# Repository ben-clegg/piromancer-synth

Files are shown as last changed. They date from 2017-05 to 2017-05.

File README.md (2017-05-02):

# piromancer-synth
A Raspberry Pi based semi-modular synthesiser, using [Pyo](https://github.com/belangeo/pyo).

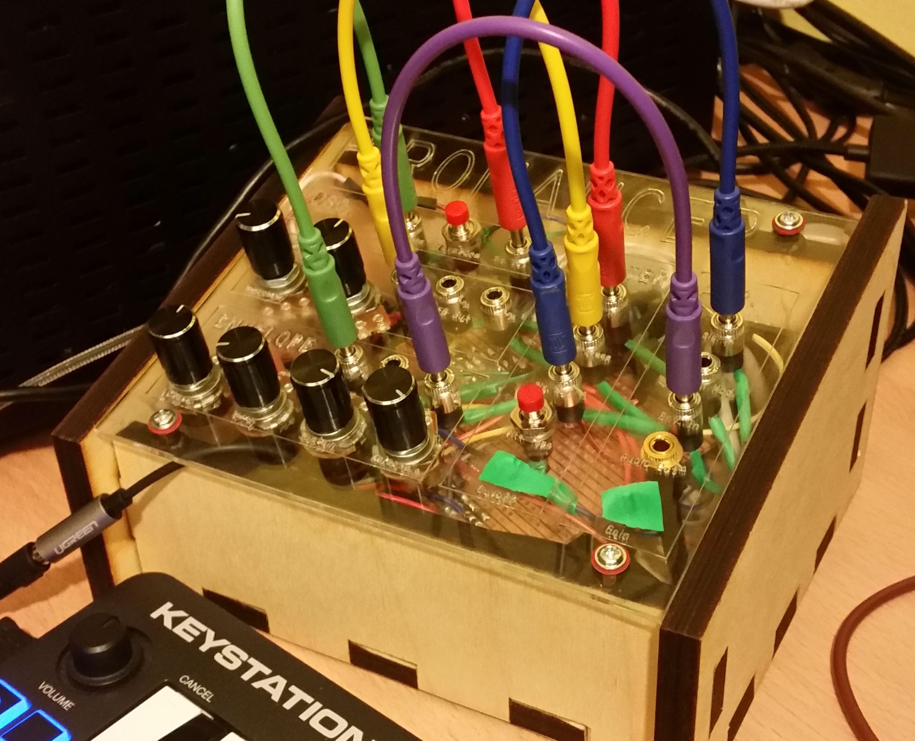
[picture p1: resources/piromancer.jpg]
The assembled synthesiser


## Licensing
All contents of this repository are released under GPLv3, with the exception of `synth/mcpaccess.py`, a modified version of [ladyada's MCP3008 driver program](https://gist.github.com/ladyada/3151375), which is released into the public domain in the same manner as the original.

## System Requirements
This software was originally designed for the original Raspberry Pi Model B, but this was confirmed to have insufficient compute power to run effectively.

However, the software functions correctly on a Raspberry Pi 3. More connections could be added due to its expanded GPIO.

## Installation
Install Jack audio server with alsa support:
```console
$ sudo apt-get install jackd2 alsaplayer-jack
```

Install [Pyo's dependencies](https://gist.github.com/pwalsh/8594869):
```console
$ sudo apt-get install python-dev libjack-jackd2-dev libportmidi-dev portaudio19-dev liblo-dev libsndfile-dev python-dev python-tk python-imaging-tk python-wxgtk2.8
```

Clone Pyo's repository, and enter its directory:
```console
$ git clone https://github.com/belangeo/pyo.git
```

[Install Pyo with Jack support, and Debian install layout](http://ajaxsoundstudio.com/pyodoc/compiling.html):
```console
$ sudo python setup.py install --install-layout=deb --use-jack
```

Provide the user with ownership of the audio output device, by adding the following to "/etc/dbus-1/system.conf":
```
<policy user="pi">
     <allow own="org.freedesktop.ReserveDevice1.Audio0"/>
</policy>
```

Clone this project's repository to the pi user's home directory:
```console
$ git clone https://github.com/BenClegg/piromancer-synth
```

## Execution
Simply run `startPiromancer.sh` to start the synthesiser. This script can be run on boot by executing `sudo crontab -e` and adding the following:
```
@reboot sh /home/pi/piromancer-synth/startPiromancer.sh >/home/pi/logs/cronlog 2>&1
```

If this "run on boot" cronjob is set, ownership of the audio output should instead be set to the root user, by changing the added code in "/etc/dbus-1/system.conf" to:
```
<policy user="root">
     <allow own="org.freedesktop.ReserveDevice1.Audio0"/>
</policy>
```

A "logs" directory should also be created inside the pi user's home directory.

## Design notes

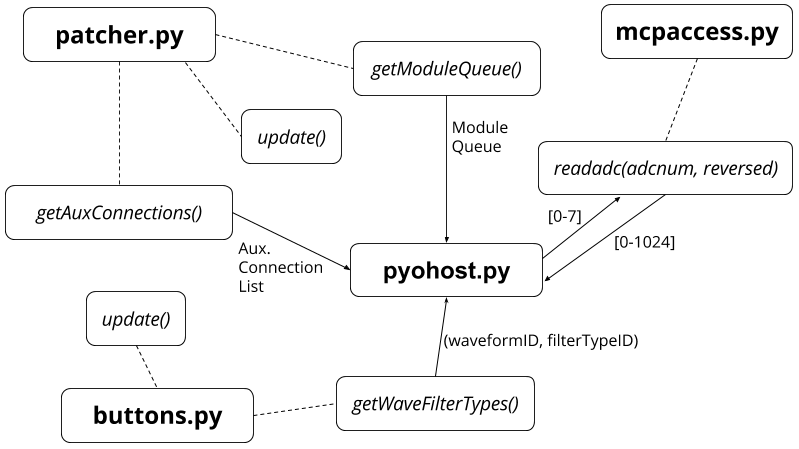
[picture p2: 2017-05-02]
resources/software-architecture.png

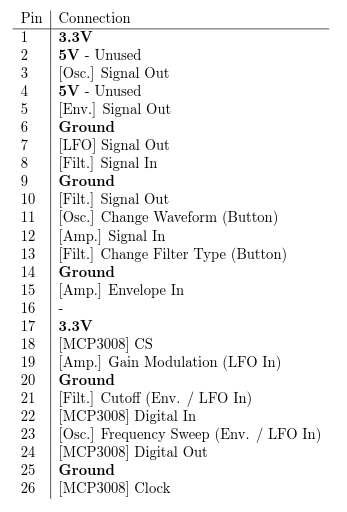
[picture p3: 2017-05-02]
resources/gpio-connections.png

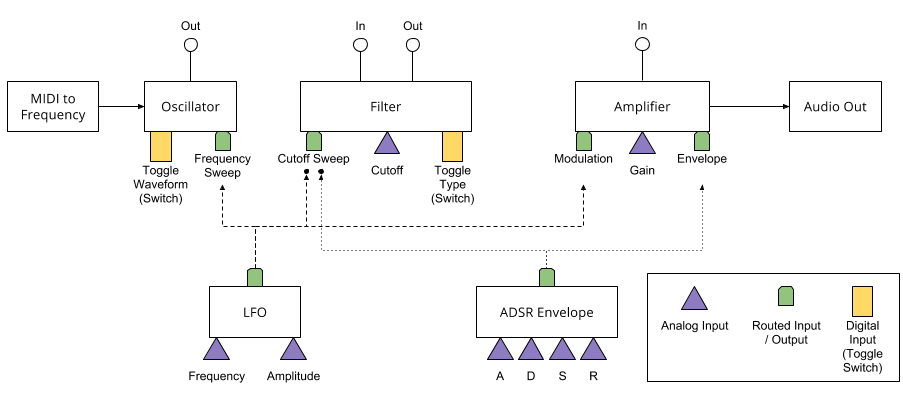
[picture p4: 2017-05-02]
resources/system-diagram.png

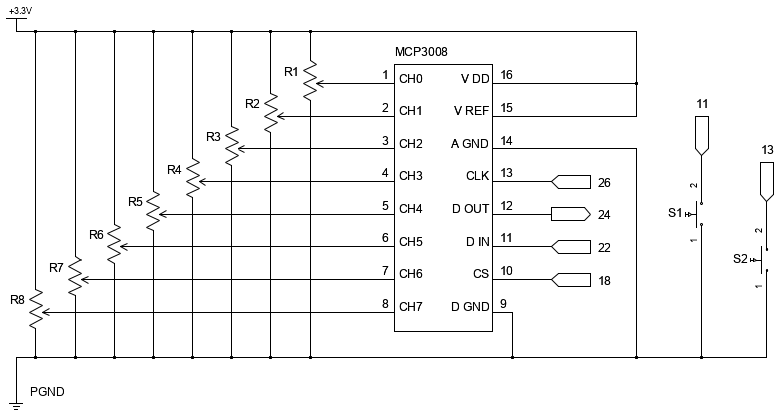
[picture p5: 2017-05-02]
resources/circuit/piromancer-circuit.png

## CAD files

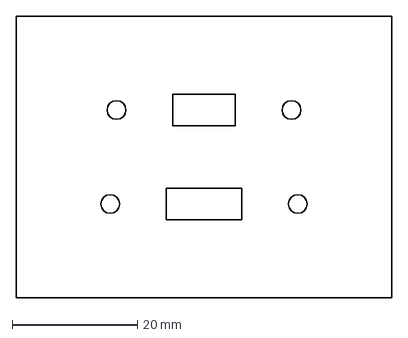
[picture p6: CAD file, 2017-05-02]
resources/dxf/usb_panel.dxf
60.0 x 45.0 mm

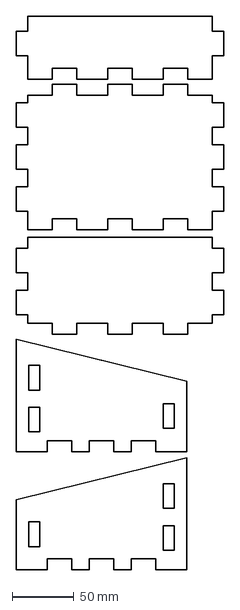
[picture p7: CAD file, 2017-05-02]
resources/dxf/plywood_panels.dxf
168.0 x 449.5 mm

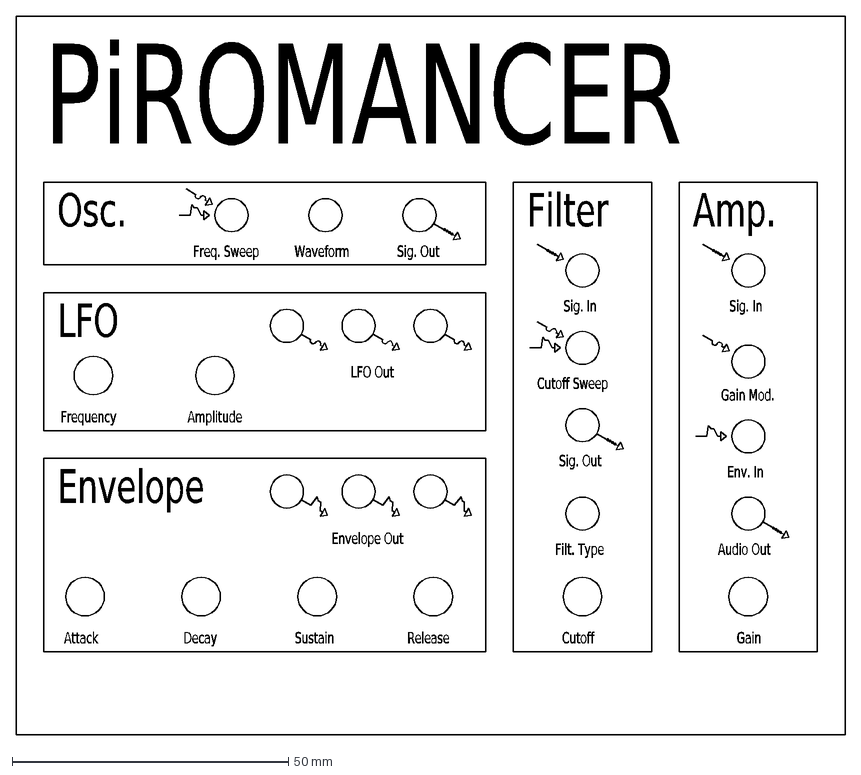
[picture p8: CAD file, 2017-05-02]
resources/dxf/patchbay.dxf
PiROMANCER
Filter
Amp.
Osc.
LFO
Envelope
Freq. Sweep
Waveform
Sig. Out
Sig. In
Audio Out
Frequency
Amplitude
Attack
Decay
Sustain
Release
Cutoff
Gain
Cutoff Sweep
Filt. Type
Gain Mod.
Env. In
LFO Out
Envelope Out

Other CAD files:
resources/sketchupModel/case_prototype_joins.skp

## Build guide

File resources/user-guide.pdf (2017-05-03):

# PiROMANCER

## User’s Guide

## 1 Introduction

PiROMANCER is a software implementation of a semi-modular monophonic synthesiser, built with a Raspberry Pi.

Monophony means that only one sound of one frequency (note) can be produced at any one time. This note can controlled using a MIDI keyboard.

Since monophonic synthesisers are often used as arpeggiators, it is recommended to play a series of notes (such as a chord) in quick succession (arpeggio).

This guide will focus on how to manipulate the synthesiser’s sound, by explaining how each module works, followed by a short guide on how to create several sounds.

## 2 Patching

Modules can be connected together using patch cables. The signal processing modules (Oscillator, Filter, and Amplifier) must be patched together by connecting one module’s Signal Out to the other’s Signal In.

The LFO and Envelope outputs can be patched into the approprate inputs on the other modules (indicated by the corresponding arrow labels).

## 3 Signal Updating

Due to the limitations of this software synthesis approach, the audio signal is not entirely realtime, and is instead updated depending on the state of the synthesiser.

If a patch is changed, added, or removed, the audio generator is updated. Also, if a button is held down, or a module’s potentiometer (knob) is turned, the generator is updated.

This update has a small latency (of around 1 to 2 seconds), where changes are detected.

## 4 Modules

### 4.1 Oscillator

The oscillator converts the MIDI’s note input to a waveform of the according frequency, creating an initial audio signal.

Frequency Sweep modifies the waveform’s frequency based upon the amplitude of an LFO or envelope input.

The Waveform button switches between different waveform types in order whilst it is held down. These waveforms are:

- SuperSaw (Roland JP-8000 Emulation)
- Sine Wave
- Triangle Wave
- Square Wave
- Pink Noise

### 4.2 Filter

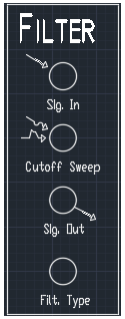
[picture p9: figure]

The filter module filters out a range of frequencies from an input signal, changing the characterstics of the sound output.

The filter’s cutoff is approximately equal the note’s frequency.

Cutoff Sweep modifies the cutoff frequency based upon the amplitude of the LFO or envelope input.

The Filter Type button switches between various filters whilst it is held down. These filters are:

- Moog Resonant Lowpass - excludes frequencies above cutoff, whilst producing resonance around the cutoff
- Resonant Bandpass - excludes frequencies outside the ‘band’ centered around the ‘cutoff’, whilst producing resonance.
- Lowpass - excludes frequencies above cutoff
- Highpass - excludes frequencies below cutoff
- Bandpass - excludes frequencies outside the ‘band’ centered around the ‘cutoff’
- Band-Reject - excludes frequencies inside the ‘band’ centered around the ‘cutoff’
- Notch - similar to Band-Reject, but with a narrow bandwidth

### 4.3 Amplifier

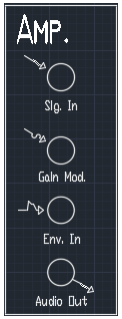
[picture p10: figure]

The amplifier effectively controls the output volume of the synthesiser, by changing the amplitude of the input signal, and sending it to the audio output.
Note: if the amplifier has no input signal, no audio is produced.
Gain Modulation changes the signal’s amplitude based upon the amplitude of the LFO. Envelope In applies the envelope to control the amplitude of the signal.

### 4.4 LFO (Low Frequency Oscillator)

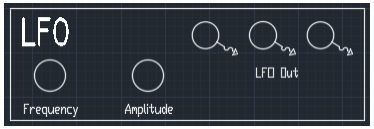
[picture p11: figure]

The LFO produces a low frequency sine wave, for use as a control signal. Note that it can only be patched into connections with the “LFO input” arrow (an arrow with a sine wave). The Frequency dial changes the sine wave’s frequency, whilst the Amplitude changes its amplitude. These values are represented between 0 and 1, but are multiplied when patched to modules, depending on the module. In general, the frequency ranges from 0.1 to 10.1 Hz. However, in the filter for example, the amplitude is multiplied by 400, to change the cutoff in this range.

### 4.5 ADSR Envelope

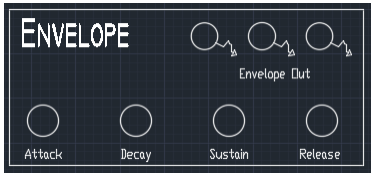
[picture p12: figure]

This module outputs a MIDI controlled ADSR (Attack, Decay, Sustain, Release) envelope, outputting its amplitude.

Note that this can only be patched into connections with the “envelope input” arrow (an arrow with an envelope amplitude outline).

Figure 1: An ADSR Envelope [1, p. 39]

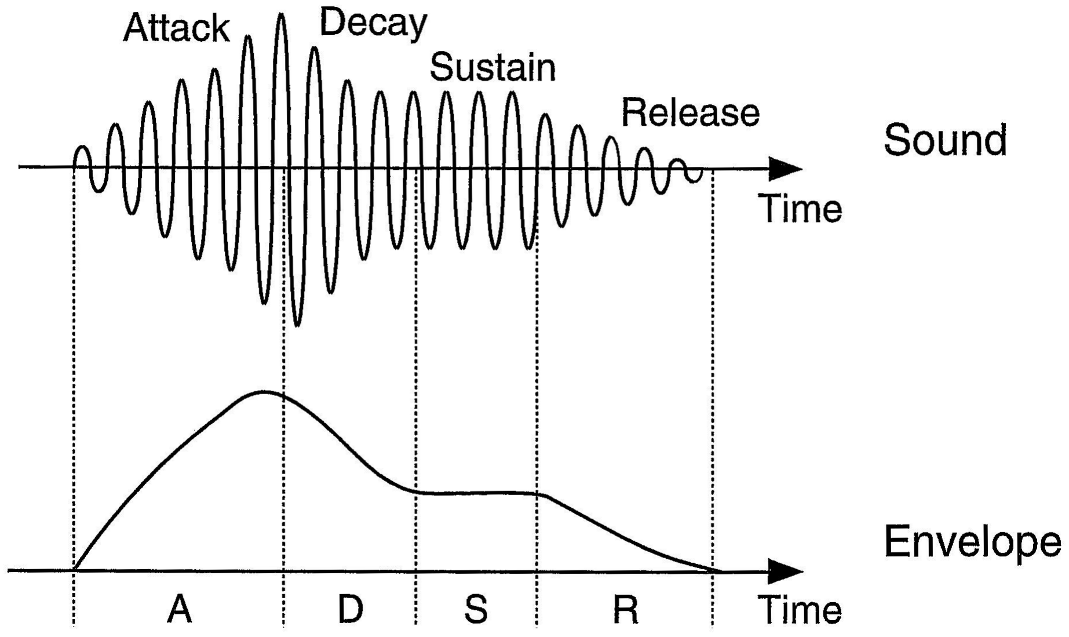
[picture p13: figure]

When a note is pressed, the envelope is triggered. Whilst the note is held, the envelope is kept at sustain. When the note is released, the release period begins.

The Attack, Decay, and Release dials control the length of each of these periods, from 0 to 1 second.

The Sustain dial controls the percentage of the input note’s velocity (how hard the key is pressed), that the sustain period’s amplitude is. This ranges from 0 to 100 percent.

## 5 Tutorial

To create a simple sound, patch the Oscillator’s Signal Out to the Amplifiers Signal In. Now press a key on the MIDI controller to play a note.

Patch the Envelope’s Output to the Amplifier’s Envelope In. Now, when a key is pressed, the note is played, but there is silence otherwise. This note can be held down to keep the envelope in “sustain”.

Try adjusting the Envelope’s controls to adjust it’s behaviour. Increasing the Attack makes it take longer to rise, for example. Decreasing the Sustain reduces the amplitude whilst the note is held.

Hold down the Oscillator’s Waveform button to change between waveforms. Release this as soon as you hear “static” (whilst holding a key on the keyboard). This is pink noise.

Next, disconnect the Oscillator to Amplifier patch. Now connect a patch from the Oscillator to the Filter, and from the Filter to the Amplifier.

The default filter is a Moog-style resonant lowpass, which surpresses frequencies above the cutoff, whilst creating resonance.

This will create a sound similar to that of wind.

Now patch the LFO’s Output to the Filter’s Cutoff Sweep. This will add a subtle “pulsing” effect to the sound.

By adjusting the LFO’s controls, this effect’s behaviour can be changed. Using a high LFO Amplitude will make this effect more prevalent.

## References

[1] Martin Russ. Sound Synthesis and Sampling, 2nd Edition. Focal Press, Linacre House, Jordan Hill, Oxford, OX2 8DP, 2004.

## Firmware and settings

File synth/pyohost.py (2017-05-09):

# Licensed under GPLv3 (https://www.gnu.org/licenses/gpl.html)

from pyo import *
from collections import deque
import os
import time
import copy

import mcpaccess
import patcher
import buttons

# Setup MCP ADC, Patching System, and Button checking
mcp = mcpaccess.MCPAccess()
patches = patcher.Patcher()
btns = buttons.Buttons()

# Setup pyo server
s = Server(audio='jack', sr=44100, nchnls=1, duplex=0, jackname='pyo')

# Print MIDI input devices
midiInputs = pm_get_input_devices()
print(midiInputs)

# Server config
s.setIchnls(0) # Disable audio in, unneeded
s.setMidiInputDevice(3) #Set midi device
s.boot() #Boot server

# Copy output to otherwise unused channel, as only using mono,
# but both speakers should output.
os.system("jack_connect pyo:output_1 system:playback_2")

s.start()

# MIDI input
midi = Notein(poly=1, scale=1) # scale=1 : pitch in Hz
                                # poly=1 : 1 stream - monophonic

# Get midi controller 7 input value. More controllers can be defined, see doc:
# http://ajaxsoundstudio.com/pyodoc/api/classes/midi.html#midictl
midi_ctl_in = Midictl(7, minscale=10, maxscale=13000, init = 1000, channel = 1)

frq = 480 # Initialise frequency
frq = midi['pitch'] #Note pitch (frequency in Hz)

# Analog inputs:
# ADC0 = [UNUSED] (Gain)
# ADC1 = [UNUSED] (Filter Cutoff)
# ADC2 = Env. Release (inverted)
# ADC3 = Env. Sustain (inverted)
# ADC4 = LFO Amplitude
# ADC5 = LFO Frequency
# ADC6 = Env. Decay (inverted)
# ADC7 = Env. Attack (inverted)

# Initialise potentiometer-controlled inputs
envValues = [0.5, 0.5, 0.5, 0.5] # Attack, Decay, Sustain, Release
env = MidiAdsr(midi['velocity'], attack=0.1, decay=0.1, sustain=0.1, release=0.1)
lfoValues = [0.4, 0.4] # Frequency, Amplitude
filt_frq = 500

def update_env():
    # Updates the globally defined envelope with appropriate MCP3008 readings
    global env
    env = MidiAdsr(midi['velocity'], attack=envValues[0], decay=envValues[1], sustain=envValues[2], release=envValues[3])

update_env()

# patch variables
sigConns = patches.getModuleQueue()
auxConns = patches.getAuxConnections()
btnVals = btns.getWaveFilterTypes() # tuple (wavetype, filttype)
# btnVals[0] = osc waveform id ; btnVals[1] = filter type

# Function definitions
def m_lfo(target=400, ampMult=1, freqMult=1):
    # Simple sine LFO.
    # Centered around target frequency
    # Other parameters multiply the MCP LFO inputs (which are 0 - 1)
    # ampMult multiplies the amplitude (amount)
    # freqMult multiplies the frequency of the LFO sine wave

    return Sine(freq=(0.1 + (freqMult * lfoValues[0])), mul=ampMult * lfoValues[1], add=target)

def m_oscillator(vel):
    # Generate source
    # http://ajaxsoundstudio.com/pyodoc/api/classes/generators.html
    local_frq = frq # set local variable to modify frequency

    # Modulate frequency with LFO
    if(patcher.CONN_LFO_OSC_SWEEP in auxConns):
        local_frq = m_lfo(frq, 100, 10)

    # Modulate frequency with Envelope
    if(patcher.CONN_ENV_OSC_SWEEP in auxConns):
        # Note: divide env by sustain (the amplitude of the sustain period)
        #       this means sustain period is always the input frequency,
        #       preventing detuning
        local_frq = local_frq * (env / env.sustain)

    # Select waveform
    if(btnVals[0] == buttons.WAVE_SUPERSAW):
        osc = SuperSaw(freq=local_frq, mul=vel) # SuperSaw wave
    elif(btnVals[0] == buttons.WAVE_SINE):
        osc = Sine(freq=local_frq, mul=vel) # Sine wave
    elif(btnVals[0] == buttons.WAVE_TRI):
        # Resistor / capacitor emulation, triangle form
        osc = RCOsc(freq=local_frq, sharp=0, mul=vel)
    elif(btnVals[0] == buttons.WAVE_SQUARE):
        # Resistor / capacitor emulation, almost square form
        osc = RCOsc(freq=local_frq, sharp=1, mul=vel)
    elif(btnVals[0] == buttons.WAVE_PINK):
        osc = PinkNoise(mul=vel) # Pink noise - freq. independent
    else:
        # Sine wave by default (prevent potential crashes)
        osc = Sine(freq=local_frq, mul=vel)
    return osc

def m_filter(input_signal, modFreq=False):
    # Apply filter
    # http://ajaxsoundstudio.com/pyodoc/api/classes/filters.html

    local_frq = midi_ctl_in # Set cutoff as midi controller 7's value
    # Note: MCP input can be used as frequency instead
    # if the cutoff potentiometer is functional

    # Modulate cutoff frequency with LFO
    if(patcher.CONN_LFO_FLT_CUTOFF in auxConns):
        local_frq = m_lfo(frq, 500, 10)

    # Modulate cutoff frequency with Envelope
    if(patcher.CONN_ENV_FLT_CUTOFF in auxConns):
        local_frq = local_frq * env

    if(btnVals[1] == buttons.FILTER_MOOG_LP):
        # Moog Resonant Lowpass
        local_frq += 50 # increase cutoff slightly, reduces filter by LP
        return MoogLP(input_signal, freq=(local_frq), res=1).out()
    elif(btnVals[1] == buttons.FILTER_BP_RESON):
        # Resonant bandpass
        return Reson(input_signal, freq=(local_frq), q=4).out()
    elif(btnVals[1] == buttons.FILTER_LP):
        # Lowpass
        return ButLP(input_signal, freq=(local_frq)).out()
    elif(btnVals[1] == buttons.FILTER_HP):
        # Highpass
        return ButHP(input_signal, freq=(local_frq)).out()
    elif(btnVals[1] == buttons.FILTER_BP):
        # Bandpass
        return ButBP(input_signal, freq=(local_frq), q = 4).out()
    elif(btnVals[1] == buttons.FILTER_BR):
        # Band reject (bandstop)
        return ButBR(input_signal, freq=(local_frq), q = 4).out()
    elif(btnVals[1] == buttons.FILTER_NOTCH):
        # Notch filter, implemented as above, but with narrow bandwidth
        return ButBR(input_signal, freq=(local_frq), q = 380).out()
    else:
        # Use Moog Resonant Lowpass by default (prevents potential crashes)
        return MoogLP(input_signal, freq=(local_frq), res=1).out()
    # Note: for band-filters, q = freq / bandwidth, so low q = high width

def m_amp(input_signal):
    # VCA simulation
    local_gain = 0.6
    if(patcher.CONN_LFO_AMP_MOD in auxConns):
        local_gain = m_lfo(0.6, 0.5, 10)
    if(patcher.CONN_ENV_AMP_ENV in auxConns):
        local_gain = local_gain * env
    if(btnVals[0] == buttons.WAVE_SQUARE):
        # Reduce volume of square wave
        local_gain = local_gain * 0.8

    local_signal = input_signal
    local_signal.setMul(local_gain)
    return local_signal


def createSignal():
    if(sigConns):
        # Connections queue not empty
        localSigConns = copy.deepcopy(sigConns)
        item = localSigConns.popleft()
        if(item == patcher.MOD_OSC):
            wav = m_oscillator(1)
            print('Found oscillator')
            return processStep(wav, localSigConns)
    print('No sig connections, returning None')
    return None

def processStep(signal, localSigConns):
    if(sigConns):
        # Connections queue not empty
        localSig = signal
        item = localSigConns.popleft()
        if(item == patcher.MOD_FILTER):
            filtered = m_filter(localSig)
            print('Found filter')
            return processStep(filtered, localSigConns)
        elif(item == patcher.MOD_AMPLIFIER):
            print('Found amplifier, returning signal output')
            #m_amp()
            #localSig.setMul(env)
            #localSig.setMul(0.6)
            return m_amp(localSig).out()
    print('No sig connections to process, returning None')
    return None

def logger():
    print("==========================")
    print("ADC 0: " + str(mcp.readadc(0)))
    print("ADC 1: " + str(mcp.readadc(1)))
    print("ADC 2: " + str(mcp.readadc(2)))
    print("ADC 3: " + str(mcp.readadc(3)))
    print("ADC 4: " + str(mcp.readadc(4)))
    print("ADC 5: " + str(mcp.readadc(5)))
    print("ADC 6: " + str(mcp.readadc(6)))
    print("ADC 7: " + str(mcp.readadc(7)))
    print("==========================")
    print("Button Values: " + str(btnVals))
    print("Signal Conns: " + str(sigConns))
    print("Auxiliary conns: " + str(auxConns))
    print("==========================")

def ctl_scan(ctlnum, midichnl):
    print(ctlnum)
    print(midichnl)

# Generate audio, applying signal processing where necessary
audio = createSignal()

# Loop to maintain server activity
while True:
    # Update envelope values
    prevEnvValues = envValues
    envValues = [mcp.readadc(7, reversed=True) / 1024,
                    mcp.readadc(6, reversed=True) / 1024,
                        mcp.readadc(3, reversed=True) / 1024,
                            mcp.readadc(2, reversed=True) / 1024]
    # Update LFO values
    prevLfoValues = lfoValues
    lfoValues = [mcp.readadc(5) / 1024, mcp.readadc(4) / 1024]
    # Update patchbay connections
    prevSigConns = sigConns
    prevAuxConns = auxConns
    patches.update()
    sigConns = patches.getModuleQueue()
    auxConns = patches.getAuxConnections()
    # Update buttons
    prevBtnVals = btnVals
    btns.update()
    btnVals = btns.getWaveFilterTypes()
    # If any connections have changed, buttons pressed,
    # or MCP readings changed, update the audio signal
    if(
            (list(prevSigConns) != list(sigConns)) or
            (list(prevAuxConns) != list(auxConns)) or
            (list(prevEnvValues) != list(envValues)) or
            (list(prevLfoValues) != list(lfoValues)) or
            (prevBtnVals != btnVals)
        ):
            # Update envelope
            update_env()
            # Regenerate audio
            audio = createSignal()
    #logger() # Uncomment to print debugging logs

    # Scan ctl, to find midi controller numbers
    #midi_controller = CtlScan2(ctl_scan)

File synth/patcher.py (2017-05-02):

# Licensed under GPLv3 (https://www.gnu.org/licenses/gpl.html)

import time
from collections import deque

import RPi.GPIO as GPIO
import os

PIN_REFRESH = 0.01 # Pin refresh delay, in seconds

# Pins
P_OSC_SIG_OUT = 3

P_FLT_SIG_IN = 8
P_FLT_SIG_OUT = 10

P_AMP_SIG_IN = 12

P_LFO_SIG_OUT = 7
P_ENV_SIG_OUT = 5

P_OSC_FMOD_IN = 23
P_FLT_CUTOFF_IN = 21
P_AMP_MOD_IN = 19
P_AMP_ENV_IN = 15

# Outputs
P_OUTPUTS = (P_OSC_SIG_OUT,
            P_FLT_SIG_OUT,
            P_LFO_SIG_OUT,
            P_ENV_SIG_OUT)
# Inputs
P_INPUTS = (P_FLT_SIG_IN,
            P_AMP_SIG_IN,
            P_OSC_FMOD_IN,
            P_FLT_CUTOFF_IN,
            P_AMP_MOD_IN,
            P_AMP_ENV_IN)

# Module ids
MOD_OSC = 1
MOD_FILTER = 2
MOD_AMPLIFIER = 3
MOD_LFO = 4
MOD_ENVELOPE = 5

# Auxiliary connection ids
CONN_LFO_OSC_SWEEP = 1
CONN_ENV_OSC_SWEEP = 2
CONN_LFO_FLT_CUTOFF = 3
CONN_ENV_FLT_CUTOFF = 4
CONN_LFO_AMP_MOD = 5
CONN_ENV_AMP_ENV = 6

class Patcher:

    def __init__(self):
        # Use board pin numbering - compatible with different RPi revisions
        GPIO.setmode(GPIO.BOARD)

        # Setup outputs
        for o in P_OUTPUTS:
            GPIO.setup(o, GPIO.OUT)

        #Setup inputs
        for i in P_INPUTS:
            GPIO.setup(i, GPIO.IN, pull_up_down=GPIO.PUD_DOWN)

        # Force outputs to low
        GPIO.output(P_OUTPUTS, GPIO.LOW)

        # Get starting signal path
        self.moduleQueue = self.findSignalPath()
        self.auxConns = self.findLfoAndEnvConns()

    def update(self):
        self.moduleQueue = self.findSignalPath()
        self.auxConns = self.findLfoAndEnvConns()

    def getModuleQueue(self):
        print("getting module queue (signal path)")
        return deque(self.moduleQueue)

    def getAuxConnections(self):
        return self.auxConns

    #Check standard signal path, returns queue of signal path, pop to find signal order
    def findSignalPath(self):
        queue = [MOD_OSC] #Signal will always start with oscillator
        GPIO.output(P_OUTPUTS, GPIO.LOW) #Set all outputs to 0/off/False
        GPIO.output(P_OSC_SIG_OUT, GPIO.HIGH) #Set initial output (oscillator) to 1/on/True
        print("locked osc")
        return self.getNextSignalModule(queue)

    #Recursive function used in findSignalPath, adds module IDs to queue
    def getNextSignalModule(self, queue):
        time.sleep(PIN_REFRESH)
        #Filter
        if(GPIO.input(P_FLT_SIG_IN)):
            queue.append(MOD_FILTER)
            GPIO.output(P_OUTPUTS, GPIO.LOW)
            GPIO.output(P_FLT_SIG_OUT, GPIO.HIGH)
            print("locked filter")
            return self.getNextSignalModule(queue) #Recurse
        #More modules can be implemented here, in the same way as filter, using an elif
        #Amplifier
        elif(GPIO.input(P_AMP_SIG_IN)):
            queue.append(MOD_AMPLIFIER)
            GPIO.output(P_OUTPUTS, GPIO.LOW)
            print("locked amp, returning")
            return queue #Don't recurse, amplifier is the last possible module in this synth
        else:
            print("amp not reached")
            return [] #Clear the queue, amplifier not reached - no audio made

    def findLfoAndEnvConns(self):
        connList = [] #Empty list of connections
        #Test LFO
        GPIO.output(P_OUTPUTS, GPIO.LOW) #Set all outputs to 0/off/False
        GPIO.output(P_LFO_SIG_OUT, GPIO.HIGH) #Set LFO output on
        time.sleep(PIN_REFRESH)
        if(GPIO.input(P_OSC_FMOD_IN)):
            connList.append(CONN_LFO_OSC_SWEEP)
        if(GPIO.input(P_FLT_CUTOFF_IN)):
            connList.append(CONN_LFO_FLT_CUTOFF)
        if(GPIO.input(P_AMP_MOD_IN)):
            connList.append(CONN_LFO_AMP_MOD)
        #Test Envelope
        GPIO.output(P_OUTPUTS, GPIO.LOW) #Set all outputs to 0/off/False
        GPIO.output(P_ENV_SIG_OUT, GPIO.HIGH) #Set LFO output on
        time.sleep(PIN_REFRESH)
        if(GPIO.input(P_FLT_CUTOFF_IN)):
            connList.append(CONN_ENV_FLT_CUTOFF)
        if(GPIO.input(P_AMP_ENV_IN)):
            connList.append(CONN_ENV_AMP_ENV)
        if(GPIO.input(P_OSC_FMOD_IN)):
            connList.append(CONN_ENV_OSC_SWEEP)
        #Return list of connection ids
        return connList

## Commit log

2017-05-09 printing second value!
2017-05-09 set filter frq to ctl value
2017-05-09 extended button wait time
